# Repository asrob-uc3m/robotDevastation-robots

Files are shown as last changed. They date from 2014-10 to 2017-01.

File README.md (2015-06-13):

robotDevastation-robots
=======================

Bundle of robot software (firmware), electronics and mechanics.

1. [rd2](rd2/)
--------
[Cómo montar el robot RD2](http://asrob.uc3m.es/index.php/C%C3%B3mo_montar_el_robot_RD2)
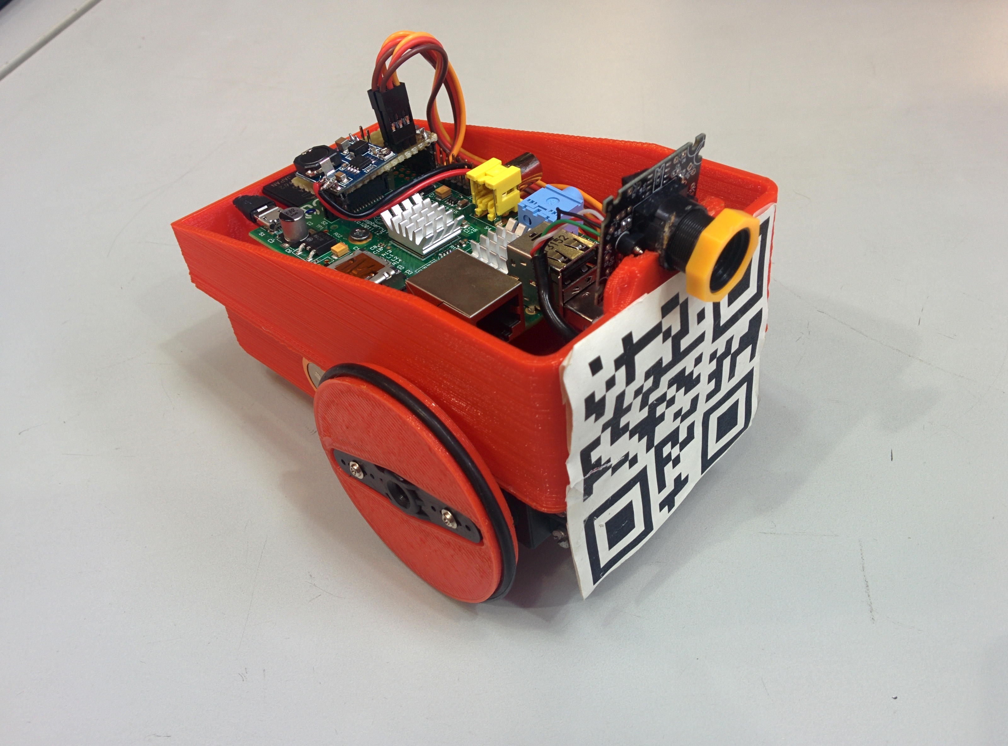
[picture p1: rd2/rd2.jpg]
RD2 robot


2. [ecro](ecro/)
--------
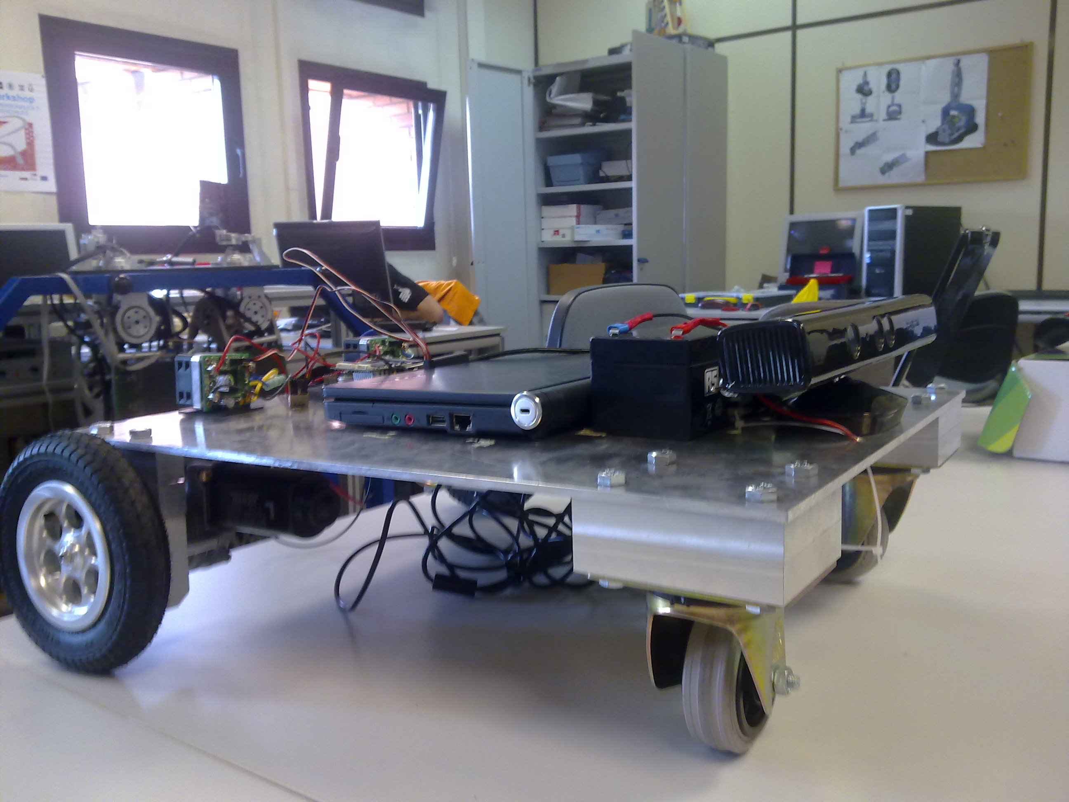
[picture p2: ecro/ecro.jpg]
ECRO robot


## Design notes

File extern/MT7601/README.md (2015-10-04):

MT7601 driver [copy from porjo]
===============================

Chipset is Ralink 148f:7601. Firmware is copied off https://github.com/porjo/mt7601/raw/master/src/mcu/bin/MT7601.bin

As of 4/Oct/2015 (reading: http://groenholdt.net/Computers/RaspberryPi/MediaTek-MT7601-USB-WIFI-on-the-Raspberry-Pi/MediaTek-MT7601-USB-WIFI-on-the-Raspberry-Pi.html), we updated to raspi kernel 4.1.9+ with: 
```bash
sudo -s
apt-get update
apt-get upgrade
rpi-update
```

Got a -2 error on direct load of firmware. The final step is (reading: https://www.raspberrypi.org/forums/viewtopic.php?t=119095&p=808311) to put the firmware .bin file (stored a copy in this directory) in /lib/firmware for raspi 4.1.9+.

Appears as wlan0, so the rest are standard configurations in /etc/network/interfaces and /etc/wpa_supplicant/wpa_supplicant.conf

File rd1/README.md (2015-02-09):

rd1
===
[Link to RD1 doxygen generated documentation](http://asrob.uc3m.es/rd1doc/index.html)
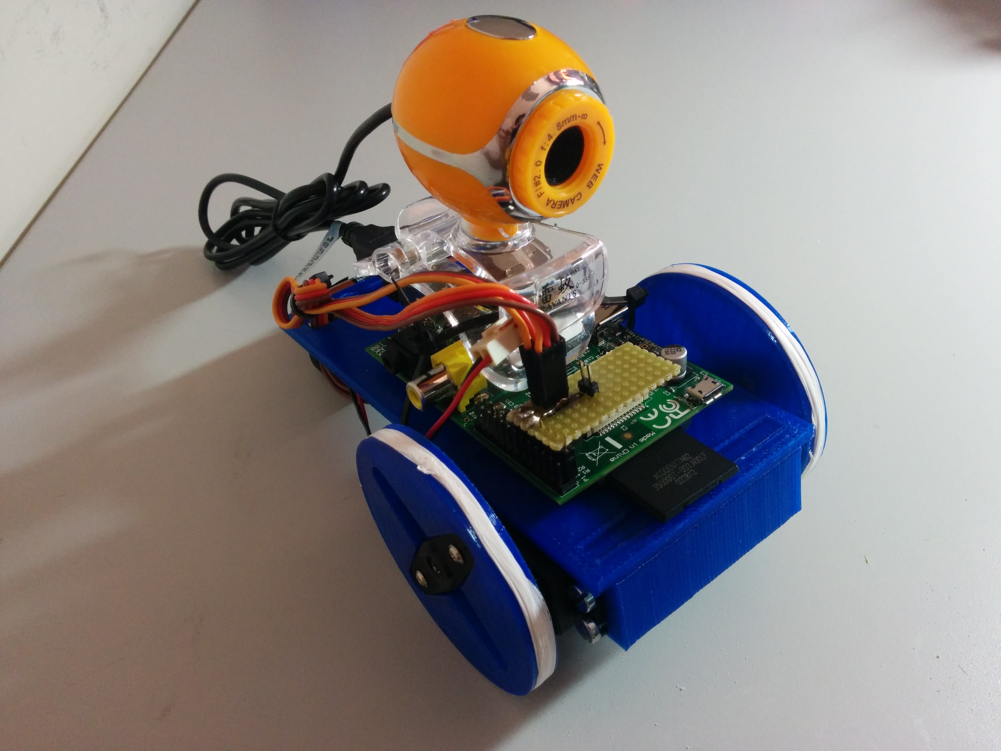
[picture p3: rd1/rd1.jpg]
RD1 robot


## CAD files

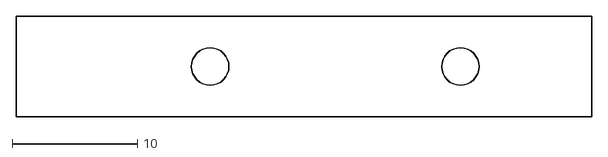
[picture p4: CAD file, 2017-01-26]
ecro/necro/motor holder.dxf
46.0 x 8.00

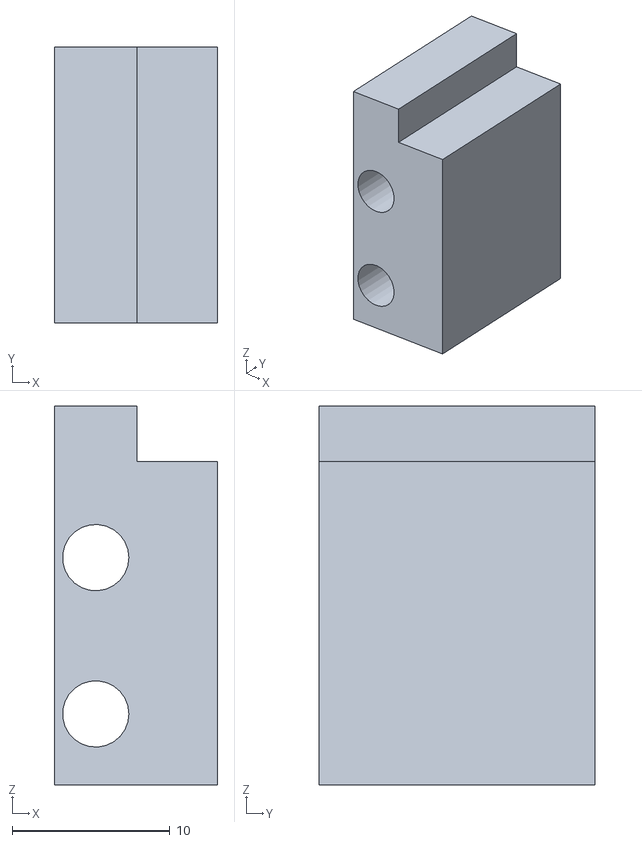
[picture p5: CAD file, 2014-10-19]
rd1/mechanics/rdSopportBack.stl
10.3 x 17.5 x 24.0

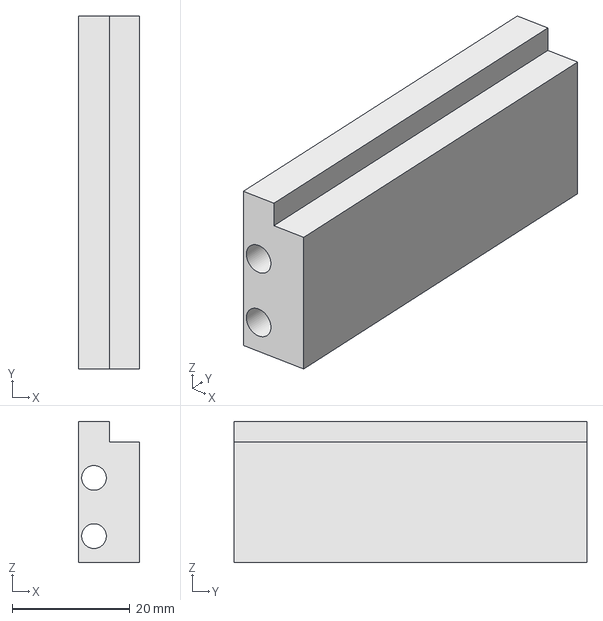
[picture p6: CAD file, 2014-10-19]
rd1/mechanics/src/rdSopportFront.FCStd
10.3 x 60.0 x 24.0 mm

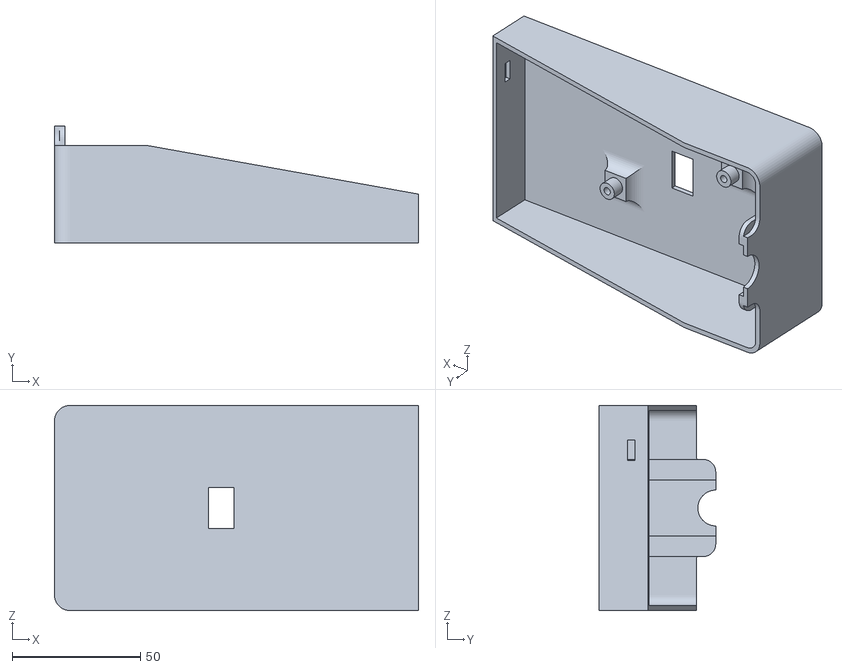
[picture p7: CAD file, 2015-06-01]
rd2/mechanics/oldversions/rd2TopV1_1.STL
142.0 x 45.5 x 80.0

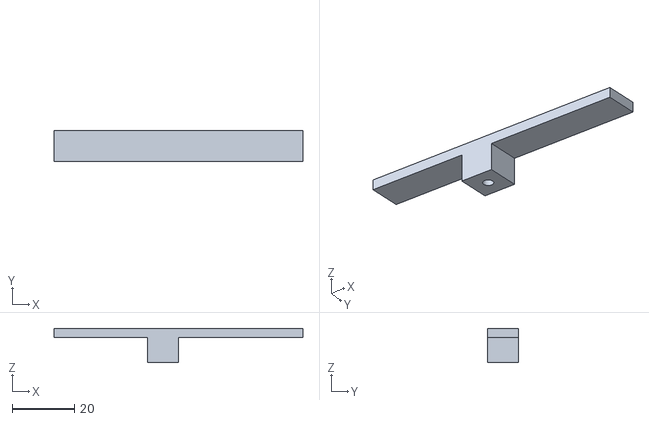
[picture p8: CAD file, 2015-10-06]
rd2/mechanics/rd2SoporteRaspberry1B_(2)V1_0.STL
80.0 x 10.00 x 11.0

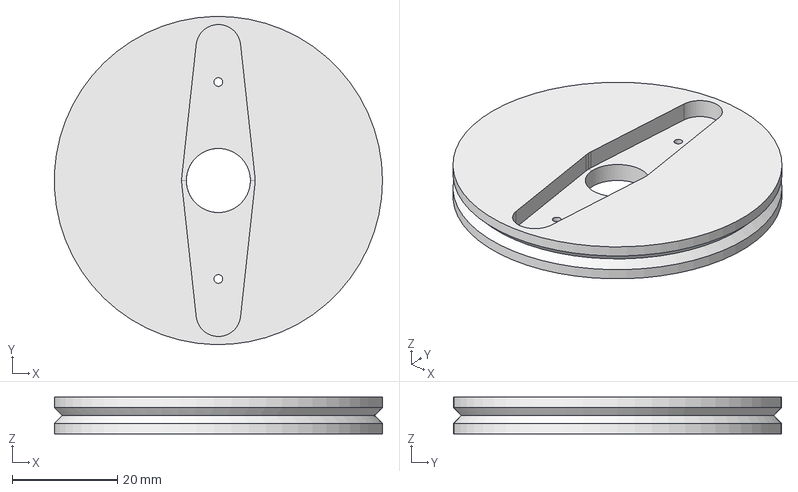
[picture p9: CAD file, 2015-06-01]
rd2/mechanics/src/rd2Wheel.fcstd
62.5 x 62.5 x 7.00 mm

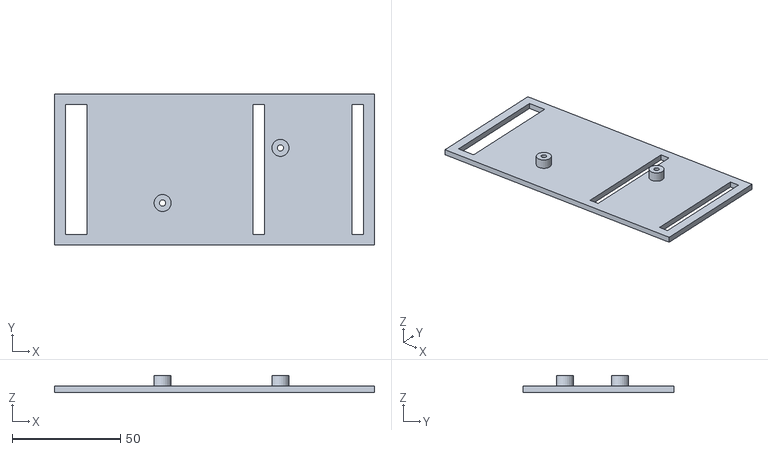
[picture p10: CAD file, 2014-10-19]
rd1/mechanics/rdTop.stl
148.0 x 70.0 x 8.00

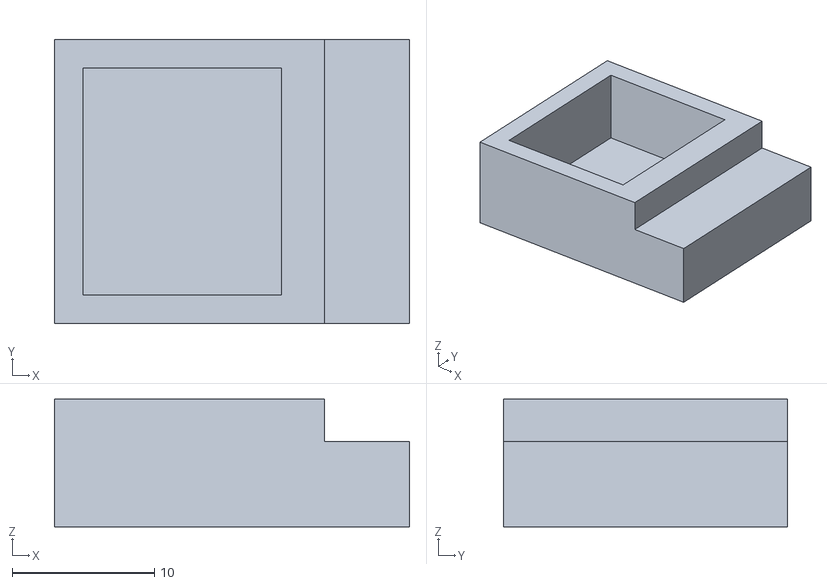
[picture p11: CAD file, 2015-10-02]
rd2/mechanics/rd2SoporteBateria_V1.0.STL
25.0 x 20.0 x 9.00

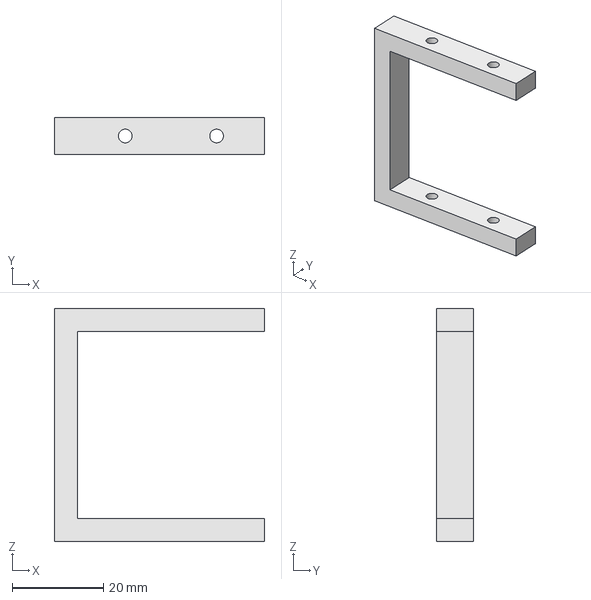
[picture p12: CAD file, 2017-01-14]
ecro/necro/motorDriverHolder.fcstd
46.0 x 8.00 x 51.0 mm

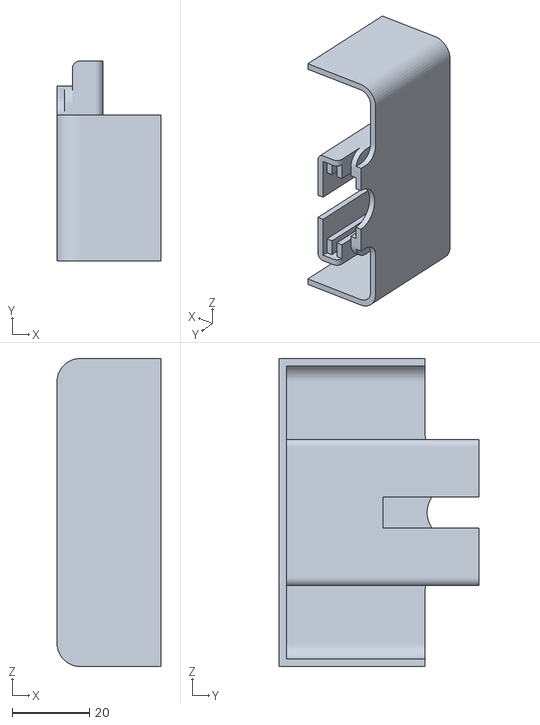
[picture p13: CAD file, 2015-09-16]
rd2/mechanics/rd2CameraTopV1_0.STL
27.0 x 52.0 x 80.0

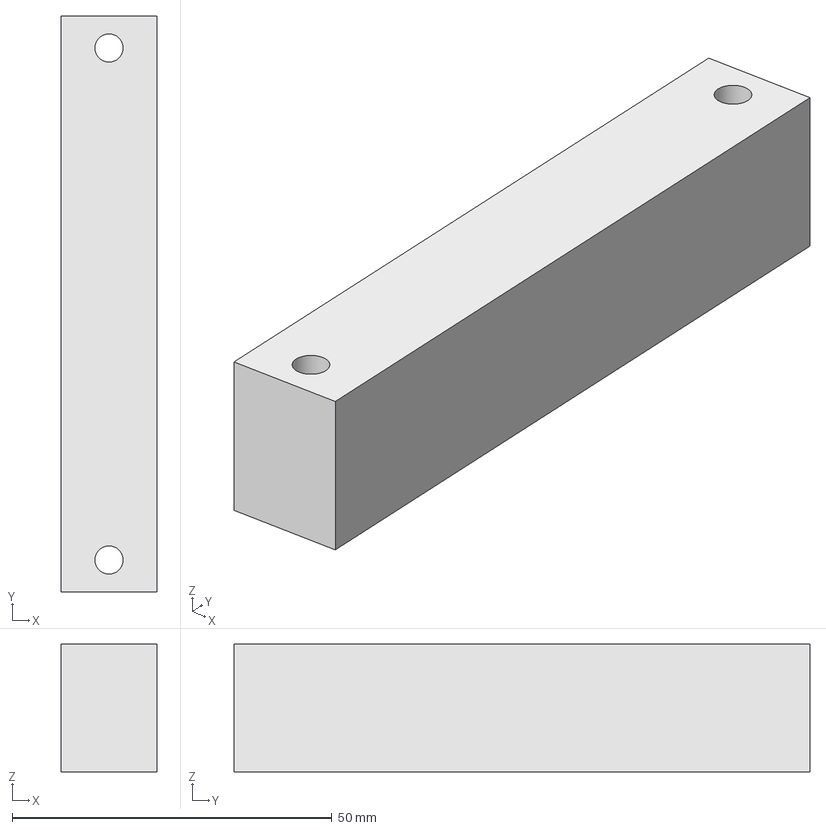
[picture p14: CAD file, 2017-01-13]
ecro/necro/supportB.fcstd
15.0 x 90.0 x 20.0 mm

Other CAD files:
ecro/necro/back template.fcstd
rd1/mechanics/src/rdSopportBack.FCStd
rd2/mechanics/rd2SoporteRaspberry1B_V1_0.STL
ecro/necro/front template.fcstd
rd1/mechanics/rdSopportFront.stl
rd1/mechanics/src/rdTop.FCStd
rd2/mechanics/rd2Wheel.STL
ecro/necro/back template.dxf
ecro/necro/front template.dxf
ecro/necro/motorDriverHolder.stl
ecro/necro/supportA.fcstd
ecro/necro/supportA.stl
ecro/necro/supportB.stl
rd2/mechanics/rd2BaseV1_0.STL

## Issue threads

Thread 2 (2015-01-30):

Upload image  of RD1 SD card.

jgvictores, 2015-01-30:
Can be uploaded as file in SF. Must set: default enable_pwmbot true, rc.local (before creating image).

David-Estevez, 2015-01-30:
@jgvictores What about making a 'distro' with everything ready / almost ready to just write the image in the sd card and play? Support to other platforms (Beaglebone, etc)?

jgvictores, 2015-01-30:
Yes, what I had in mind is getting what we already have (a raspian with launchRd1), set rc.local to launch launchRd1 (maybe through yarprun), and uploading that plug-and-play image (fsa  and/or raw dd).
It would be great to set up an apt-ppa, and port to many platforms. Let's keep this issue for keeping track of the rd1-raspian image, and open new issues for specific ports.

jgvictores, 2015-02-01:
Should check  tools that offer the possibility of a graphical front-end (Clonezilla, perhaps?).

David-Estevez, 2015-02-01:
A graphical front-end for uploading the image to the SD card? I used Clonezilla for backups in the past, and you still need to boot Clonezilla for that, so you have to write Clonezilla on another device.

Unetbootin worked for me when writing Live USBs from ISOs, but I guess it does not work the same way with Raspberry Pi images

jgvictores, 2015-02-08:
Two comments regarding deployment:
- I believe defaulting to using a yarprun daemon on the robots will prove useful. Yarprun is a server to launch and monitor programs remotely. This way, the robotDevastation PC can have all the setup options, and launch the corresponding robotDevastation-robots program with the correct arguments.
- We should consider Docker Hub Registry (https://registry.hub.docker.com/). Check the following currently ongiong thread: http://ros-users.122217.n3.nabble.com/Givving-ROS-an-Official-DockerHub-Image-td4021623.html

David-Estevez, 2015-02-08:
The daemon seems to be a good choice, this way the robot could be managed directly from the player's PC.

I didn't know about Docker, what a nice concept! We could definitely give in a try for shipping the game.

jgvictores, 2016-04-20:
The issue of the title has been closed a while ago (http://asrob.uc3m.es/index.php/C%C3%B3mo_montar_el_robot_RD2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), so closing.

Closed 2016-04-20.

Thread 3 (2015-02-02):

Have a usable and documented robot.

jgvictores, 2015-02-02:
Both rd1 and rd2 look like good candidates, but we need documentation on construction and installing software too for anyone to build it.

Rodriwp, 2015-02-02:
I think we must create documentation for rd2 ( with raspberry pi) as the standard robot for everyone and documentation for the "Ardubot module" that enables anyone with arduino and robotics skills to implement robot devastation in any project without linux skills or advance programming skills.

David-Estevez, 2015-02-02:
I would argue that controlling the board's GPIOs with python requires less skills than developing on Arduino, as well as reduce costs by removing the need of adding an extra board.

Anyway, this issue refered to the need of having any usable robot with documentation, rd2 (+ardubot or whatever is finally used) is perfectly suitable to solve this issue.

Btw, we have thought about using the new [Raspberry Pi 2](http://www.raspberrypi.org/raspberry-pi-2-on-sale/) or the [ODroid C1](http://www.hardkernel.com/main/products/prdt_info.php) as our choice of SBC, as it seems that that format of board with those holes and connectors is likely to become a standard among SBCs, and that will make easier to switch between one or other.

jgvictores, 2016-04-20:
Done at http://asrob.uc3m.es/index.php/C%C3%B3mo_montar_el_robot_RD2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, duplicate of #5.

Closed 2016-04-20.

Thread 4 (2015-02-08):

Battery Status

Rodriwp, 2015-02-08:
For the rd2 version with ardubot will be nice to have feedback about the state of the batteries. This version use lipo bateries for the motors and is dangerous to discharge below a certain voltage(the value depends on the number of cells)

Smallest robots probably, will have an approximated voltage measure. For the biggest robots that use ardubot, there exists an voltage regulator,amperage measure and voltage measure that cost about 10 euros.

Here is a link http://www.dx.com/es/p/zndiy-bry-apm2-5-2-apm2-6-power-module-v1-0-output-w-bec-3a-xt60-plug-black-red-342902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

http://copter.ardupilot.com/wiki/common-measuring-battery-voltage-and-current-consumption-with-apm/?lang=es
- [ ] Software (implementation)
- [ ] Hardware (assembly)

Rodriwp, 2016-10-22:
In the software part it will be useful to encapsulate in RdRobotLib some function about robot status. Right know we are only planning to  take information from the robot about battery status, but it should support in the future more robot information (gps position, gyroscope,etc).

Im working on it right know

Rodriwp, 2016-10-22:
I propose several states for the battery that are set using an integer.

- NOBATERRY for robots that don't use batteries.
- A value between 1 and 100 for the percentage of battery if is discharging
-  A value between 101 and 200 for the percentage of battery if is charging

jgvictores, 2016-10-22:
I was actually going to propose implementing the YARP [IBattery](http://www.yarp.it/classyarp_1_1dev_1_1IBattery.html) interface. Here's the raw of the file:
https://github.com/robotology/yarp/blob/e0ca8e6f73c37286734d06e3afb8015529ee36b9/src/libYARP_dev/include/yarp/dev/IBattery.h
I've seen they are implementing a yarpbatterygui, so this can be a good thing.

jgvictores, 2016-10-22:
Updated link in previous comment.

David-Estevez, 2016-10-22:
+1 to the existing interface.

IMHO, I think the focus should shift from the frontend side to the robot backend. It has no sense to implement the software support for battery status if we are not currently able to measure the battery status.

Rodriwp, 2016-10-22:
+1 to the existing interface too

@David-Estevez we already have a battery mesuared system. There is one in our closet

[APM POWER MODULE](https://es.aliexpress.com/store/product/Free-Shipping-airplane-APM-Power-Module-5-3V-DC-BEC-XT60-Connectors-for-ARDUPILOT-APM-2/2218173_32711885701.html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,searchweb201602_3_10065_10068_10069_10084_10083_10017_10080_10082_10081_10060_10061_10062_10056_10055_10054_10059_10078_10079_10073_10070_421_420_10052_10053_10050_10051,searchweb201603_7&btsid=33a392cf-9d4d-4365-a3bb-e7da754c687b)

This module is at the same a time a power regulator the will solve our two battery problem and it have also voltage and current mesuare.

And the best thing, it only cost 5 $

jgvictores, 2016-10-22:
> And the best thing, it only cost 5 $

:joy::joy::joy:

David-Estevez, 2016-10-22:
What I meant is that the most sensible approach, in my opinion, is a bottom-up approach: hardware -> firmware -> software , not the other way around.

Nevertheless, feel free to add support for such a magnificent piece of Chinese engineering, it will definitely be useful to have such data.

jgvictores, 2016-11-09:
@Rodriwp Could you please link to the current selected hardware?

Rodriwp, 2016-11-09:
I started some test with this device. It have six pins with the following pinout:

- 1 VCC +5
- 2 VCC +5
- 3 VCurrent
- 4 VBat
- 5  GND
- 6  GND
[Imagen Dispositivo](http://img2.banggood.com/thumb/large/upload/2014/03/SKU119430.0.jpg)
[PinOut](http://4.bp.blogspot.com/-L-IGAUheI_w/VfKFZQ2tWRI/AAAAAAAABMM/ztc3dOWLcUo/s1600/APM%2BPower%2Bmodule%2Bpinout.jpg)

Also, I have a code that can read the voltage of a battery using an analog input. As some of our robots, don't have analog input(raspberry pi), we can use an atiny85 to map de data and send via serial port.

This module is at the same time a power regulator, so we can use the same baterry for the motors and the raspberry pi.

Rodriwp, 2016-11-09:
@jgvictores  this is a link to the product [POWER MODULE 1.0](https://es.aliexpress.com/store/product/Wholesale-1pcs-2-5-APM-Flight-Controller-Power-Module-V1-0-Output-BEC-3A-Deans-T/603538_32547524353.html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,searchweb201602_2_10092_10091_10090_10088_10089,searchweb201603_1&btsid=2feb4319-315b-4998-b77c-53a0af2943b0)

jgvictores, 2016-11-09:
@Rodriwp Great, now could you link to a URL that describes the pinout?

Rodriwp, 2016-11-09:
@jgvictores you can find the schematics of the module [here](https://upverter.com/erlerobot/a9bdc322cf64f8a1/APM25-Power-Module-v10/)

Rodriwp, 2016-11-09:
@jgvictores in a comment below you cand find the pinout. Here the link [PinOut](http://4.bp.blogspot.com/-L-IGAUheI_w/VfKFZQ2tWRI/AAAAAAAABMM/ztc3dOWLcUo/s1600/APM%2BPower%2Bmodule%2Bpinout.jpg)

Rodriwp, 2016-11-09:
Extra information about our device:
The schematics of the module [here](https://upverter.com/erlerobot/a9bdc322cf64f8a1/APM25-Power-Module-v10/)

jgvictores, 2016-11-09:
@Rodriwp As general questions related to the battery (NOT the power module):
1. What is the battery voltage range (Vmin-Vmax) we are expecting to read?
2. What is the battery current range (Imin-Imax) we are expecting to read

Rodriwp, 2016-11-23:
1. We are expecting between 3.7 and 4.1 volts per celd, and we excpected 2 and 3 cell bateries
2. We are expecting between 0 A and about 0.6 A for standar robots. More powerfull robots as RD glory, needs about 1.2A. We should support both ranges.

jgvictores, 2016-11-23:
Please focus on one specific model. Which one?

Rodriwp, 2016-11-23:
We can focus on 2 cells 0.8 max A robots

David-Estevez, 2016-11-23:
Please specify also the estimated current comsuption per device (e.g. SBC, motors (nominal and allowed peaks), camera, etc).

Rodriwp, 2016-11-23:
The RD2 have the following parts:

1. Motors: 200mA peak 300mA x 2 motors
2. Camera: 200mA
3. RaspberryPi: 800mA
4. WifiModule: 215mA

Total: 1.8 A of current expected.

jgvictores, 2016-11-23:
Okay, so that would be...
1. Sum of peak: 1.815 A
2. Sum of nominal: 1.615 A

Rodriwp, 2016-11-23:
The current arquitecture connects the motors directly to the battery, and all the other stuff through a 5V regulator.

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

jgvictores, 2016-11-23:
Could you please provide a link to the motors, which includes the maximum voltage?

Rodriwp, 2016-11-23:
The operating voltage is between 4.8 and 7.2

Rodriwp, 2016-11-23:
I propouse to use this solution
http://controlrobotics.rodrigomompo.com/2013/10/tutorial-battery-charge-indicator.html

jgvictores, 2016-11-23:
> The operating voltage is between 4.8 and 7.2

Seems the schematic would burn these motors.

> I propouse to use this solution

I understand you do not like your original proposal(s). Could you please upload an image of a new version of the schematic (including all components e.g. motors and RasPi) as a post on this issue?

Rodriwp, 2016-11-23:
As the current configuration of RD is deprecated, we should develop for RD ambassador #21.
Furthermore, I think the batery status, for simplicity could take into account only voltage measure.

For this aproach we only need to measuare the battery voltage before all the robot. So, we really don't care about the complete configuration.

jgvictores, 2016-11-23:
> As the current configuration of RD is deprecated, we should develop for RD ambassador #21.
Furthermore, I think the batery status, for simplicity could take into account only voltage measure.

The robot was never specify in this issue. Could you specify the robot in this issue?

BTW, there are no deprecated RD configurations I'm aware about. Could you please point to this fact if it exists?

> For this aproach we only need to measuare the battery voltage before all the robot. So, we really don't care about the complete configuration.

That's a design decision you can specify as the creator of this issue. Could you specify this as your objective?

Rodriwp, 2016-11-23:
RD2 use two batteries. Our current developments use only one battery. This is the reason why I said is deprecated

The objective of this issue is to measure the voltaje of the battery, as a digital output. We want to know when the battery is near to the dangerouts zone (7.6 v) and when we need to disconect the battery (7.4v)

jgvictores, 2016-11-23:
> RD2 use two batteries. Our current developments use only one battery. This is the reason why I said is deprecated

RD2 not dead! :smile:
I would definitely not DEPRECATE [our most documented robot](http://asrob.uc3m.es/index.php/C%C3%B3mo_montar_el_robot_RD2) yet.

> The objective of this issue is to measure the voltaje of the battery, as a digital output. We want to know when the battery is near to the dangerouts zone (7.6 v) and when we need to disconect the battery (7.4v)

This seems reasonable, at least to me.

David-Estevez, 2016-11-23:
> The objective of this issue is to measure the voltaje of the battery, as a digital output. We want to know when the battery is near to the dangerouts zone (7.6 v) and when we need to disconect the battery (7.4v)

Usually when using the robot the battery voltage decreases. So 7.6V would never be a problem in normal use. And if we disconnect at 7.4V (the typical battery value)  we wont ever play.

Rodriwp, 2016-11-23:
We should check the values

We already have one module working, we can use it for testing the firmware and software implementation

jgvictores, 2016-11-23:
What do you mean by checking?

Which module do you mean?

Rodriwp, 2016-11-23:
We should adjust the alarm values to the safety lipo operation range

The circuit that is explain in http://controlrobotics.rodrigomompo.com/2013/10/tutorial-battery-charge-indicator.html, we have that circuit with us

jgvictores, 2016-11-23:
> We should adjust the alarm values to the safety lipo operation range

What do you mean by  that?

> The circuit that is explain in http://controlrobotics.rodrigomompo.com/2013/10/tutorial-battery-charge-indicator.html, we have that circuit with us

Could you please provide a schematic that includes the components (a paper version like the previous would do)?

Rodriwp, 2016-12-15:
I won't continue this idea as it lead to stalemate

David-Estevez, 2017-06-14:
I guess it is the moment to really solve this.

David-Estevez, 2017-06-14:
https://www.youtube.com/watch?v=md3B3I7Nmvw

jgvictores, 2017-06-15:
> Lashing out the action, returning the reaction
[...]
Battery is found in me
Battery
Battery

JavierIH, 2017-06-15:
:popcorn:

jgvictores, 2018-05-13:
Ongoing PR: https://github.com/robotology/yarp/pull/1583

jgvictores, 2018-06-22:
Moved to https://github.com/asrob-uc3m/robotDevastation-research/issues/11

Closed 2018-06-22.

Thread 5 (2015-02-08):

RaspberryPi + rd1 Set Up Guide

Rodriwp, 2015-02-08:
Will we nice to have a complete guide about seting up raspberrypi without using the image of rd1. The documentation also will help with rd2 with ardubot   and ardubot versions.

jgvictores, 2015-02-09:
This issue is almost a duplicate of https://github.com/asrob-uc3m/robotDevastation-robots/issues/3, but we can use it to focus on RD1. For now the two relevant links are:
- http://asrob.uc3m.es/rd1doc/rd1_install_on_raspbian_7.html
- http://asrob.uc3m.es/index.php/C%C3%B3mo_montar_el_robot_RD1

jgvictores, 2015-06-03:
RD1 depreciated. Docuemented RD2 at http://asrob.uc3m.es/index.php/C%C3%B3mo_montar_el_robot_RD2.

Closed 2015-06-03.

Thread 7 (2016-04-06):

RD3 and RDTurret (...and other ideas)

JuanFdelArco, 2016-04-06:
New robot design assigned to Juan F. del Arco.

David-Estevez, 2016-04-06:
@JuanFdelArco when you are more o less done with the design of the new RDTurret I can help you setup a stereo camera to have a 3D First Person View of the Turret's point of view with a phone (and old project of mine) :smile:

JuanFdelArco, 2016-04-13:
Idea #1:
- Omnidirectional robot.
- There are QR's on each corner.
- It can be combined with RDTurret for two players on one robot.

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

David-Estevez, 2016-04-13:
@JuanFdelArco Very cool robot!!

David-Estevez, 2016-04-13:
Suggestion for the wheels:
* http://www.robotshop.com/en/58mm-plastic-omni-wheel-lego-nxt-servo.html
* http://www.robotshop.com/en/48mm-omniwheel-lego-nxt-servo.html

David-Estevez, 2016-06-01:
Looking for "robot tracks" in aliexpress: http://es.aliexpress.com/store/product/Free-shipping-smart-Car-Smart-Car-Chassis-Robot-Tracking-Sensor-Coded-Disc/1460814_32288410589.html

David-Estevez, 2016-06-02:
More ideas: use stock batteries from consumer electronics products (such as cameras, smartphones, etc)

Example: http://es.aliexpress.com/store/product/2pcs-Battery-Charger-7-4V-1800mAh-EN-EL9-EN-EL9-ENEL9-Rechargeable-Camera-Battery-For-Nikon/1163277_1797911243.html

David-Estevez, 2016-06-14:
Even more ideas: [Cool Fighting Robots](https://www.youtube.com/watch?v=BgOG5te3jlc) via @JavierIH

(Maybe all this info should be moved to [robotDevastation-research](https://github.com/asrob-uc3m/robotDevastation-research))

jgvictores, 2018-06-22:
This issue was moved to asrob-uc3m/robotDevastation-research#10

Closed 2018-06-22.

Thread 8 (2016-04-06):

Robot (first time) configuration through access point

David-Estevez, 2016-04-06:
Suggestion for a cool improvement: When you first turn on you robot, it creates a wireless access point that you can use to configure the robot and tell which network it should connect to. Then, the robot switches off this access point and connects to the game network.

jgvictores, 2017-02-17:
Blocked by #29

jgvictores, 2017-03-29:
Unblocked as #29 closed.

The proposed interface should modify the installed versions of [these launch files](https://github.com/asrob-uc3m/robotDevastation-robots/tree/fd9f832c0a2a62b61b27aa2062626e6d0901e8bf/share/launch), which are currently hard-coded to be used from `/usr/local/share/robotDevastation-robots/contexts/launch/` in [the services](https://github.com/asrob-uc3m/robotDevastation-robots/tree/fd9f832c0a2a62b61b27aa2062626e6d0901e8bf/scripts/etc/service).

As an additional reference, we still have [this web snippet](https://github.com/asrob-uc3m/robotDevastation-robots/tree/fd9f832c0a2a62b61b27aa2062626e6d0901e8bf/web), but it lacks editing permissions on the installed files.

jgvictores, 2018-04-13:
Historic from http://asrob.uc3m.es/index.php/C%C3%B3mo_instalar_el_software_de_RD1_sobre_Raspbian_7 ([perma](http://asrob.uc3m.es/index.php?title=C%C3%B3mo_instalar_el_software_de_RD1_sobre_Raspbian_7&oldid=11274)):
```
git clone https://github.com/asrob-uc3m/robotDevastation-robots.git  # Download the robotDevastation-robots software from the repository
cd robotDevastation-robots/rd1/software; mkdir build; cd build; cmake ..  # Configure the robotDevastation-robots RD1 software
make  # Compile
sudo make install  # Install :-)

#- Extra robotName config server:
sudo apt-get install php5
sudo ln -s web/index.php /var/www
sudo ln -s web/save.php /var/www
```

jgvictores, 2019-05-07:
Setting up a Raspberry Pi as an access point in a standalone network (NAT): https://www.raspberrypi.org/documentation/configuration/wireless/access-point.md

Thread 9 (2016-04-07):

Decrease video transmission latency

Rodriwp, 2016-04-07:
In order to decrease latency, test if this modules are better than the current ones

David-Estevez, 2016-04-07:
ESP8266 modules aren't USB WiFi dongles, but bridges between USARTs and TCP/UDP sockets on the PC side. Therefore, I doubt that they can be used to stream images from the raspberry pi (and if they can, it's probably through a even slower connection).

To reduce latency (if that is the issue), two approaches can be followed:

1. Upgrade cheap WiFi dongle with a higher quality (Bandwidth) one. I can lend you one ASUS N11 dongle I have at home for testing.
2. Try to view a mjpeg stream directly using mjpg-streamer on the raspberry pi. If using only mjpg-streamer the video doesn't have any latency, this latency might be introduced by the image processing done on the PC (not related to WiFi hardware).

jgvictores, 2016-04-07:
Option 2 involves invoking mjpg_streamer on the raspi, as in:
`mjpg_streamer -i "input_uvc.so -f 15 -d /dev/video0 -y" -o "output_http.so -p 8080"`
It's good because we'd drop some wrapping processes involved in using opencv and yarp on the raspi side. We could then hook the stream on the robotDevastation (PC client) side as we did in https://github.com/robotology/yarp/issues/254 (with a Darwin-op robot using mjpg_streamer: https://sourceforge.net/projects/mjpg-streamer/).

David-Estevez, 2016-04-07:
Another possible related software improvement could be print the received images _before_ further processing (to have a higher update rate) and process only a few frames (use tracking to interpolate enemies between frames).

jgvictores, 2016-04-08:
Ok to change the topic to **Decrease video transmission latency**?

Rodriwp, 2016-04-10:
RaspiMjpeg seems to solve the problem.
https://www.raspberrypi.org/forums/viewtopic.php?f=43&t=61771
Next sesion I will test it

David-Estevez, 2016-04-23:
Some new points:

1. Last wednesday we tested the wifi connection and it was ok between two PCs on the same LAN, so the problem must be related to the robot. Next thing to try is changing the wifi dongle by a faster one, to check if high latency is related to wifi dongle bandwidth.
2. Related to use the ESP8266 as wifi dongle, I have found the following resources:
    * https://hackaday.io/project/8678-rpi-wifi
    * https://github.com/al177/esp8089

    It is a difficult issue, and I'm not sure that this solution is faster that the current chinese wifi dongle.

Rodriwp, 2016-11-09:
The next test we need to perform is with RD2 Black and @David-Estevez expensive wifi module. So, we can discard that our chinese hardward is the problem

Rodriwp, 2016-11-23:
@David-Estevez  and @jgvictores Did you realize if RD ambassador decrease transmission latency ?

jgvictores, 2016-11-23:
Yesteday at https://github.com/asrob-uc3m/actas/issues/36 latency was surprisingly low.

It would be great if you could stay focused on #4 for the time being.

jgvictores, 2018-05-08:
Just for the record, I've read one of the greatest improvements on `Raspberry 3 B+` is on comms, note the 2.4GHz and 5GHz IEEE 802.11.b/g/n/ac wireless LAN spec: https://www.raspberrypi.org/products/raspberry-pi-3-model-b-plus/

jgvictores, 2018-06-22:
This issue was moved to asrob-uc3m/robotDevastation-research#13

Closed 2018-06-22.

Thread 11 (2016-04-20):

[cmake] Set up cross compiling for raspi

jgvictores, 2016-04-20:
[cmake] Set up cross compiling for raspi

help: https://blog.kitware.com/cross-compiling-for-raspberry-pi/

David-Estevez, 2016-10-19:
More info: http://hackaday.com/2016/09/01/how-to-use-docker-to-cross-compile-for-raspberry-pi-and-more/

jgvictores, 2018-06-22:
This issue was moved to roboticslab-uc3m/yarp-devices#186

Closed 2018-06-22.

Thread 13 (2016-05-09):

Use ARM Cortex M

Rodriwp, 2016-05-09:
I buy for 2$ an ARM Cortex M3. As this hardware seems to be more powerfull, let's test if we can do ip video with it. Probably a bundle arm cortex m3 + esp8266 could be the core of the new low cost robots.

If M3 is not powerfull enoght we can test M4 and M7. With this we can create the robot devastation board.

David-Estevez, 2016-05-09:
This comment has two parts: one in which I warn you about why this is difficult and another in which I provide you some resources just in case you still want to try to do this.

First of all, if you want to have a achieve transmission rate, you won't be using Arduino-like libraries to program the ARM chip, but manipulating raw registers and memory. You will have to find out what is the protocol for image transmission in the camera module, what is the image format, and what is the compression algorithm used (if it has any). Then,  you will have to implement a socket-based streamer to transmit the image data. You may have or not to encode the data in each packet, but still you will have to implement all the streamer code (take a look of mjpg-streamer code, for instance) in the ARM chip. Take into account also debugging of the code, which will be also difficult as it involves several pieces of hardware and image processing.

If after all of this you still want to build this device, here you have some resources that might be useful for you:

* This [post in hackadaty](https://hackaday.com/tag/wifi-camera/) shows an existing implementation of a DIY WiFi camera done with the M3 in the ESP8266 board.
* This comment in other related issue: https://github.com/asrob-uc3m/robotDevastation-robots/issues/9#issuecomment-213746159 gives you some clues about the WiFi transmission part.

David-Estevez, 2016-05-09:
FYI: http://es.aliexpress.com/store/product/WIFI-1280-x-960P-1-3MP-Mini-IP-Camera-Indoor-Black-Security-Camera-Night-Vision-ONVIF/415422_32573773191.html

Rodriwp, 2016-05-09:
Probably It will be nice to use 0V7670 camera. It cost around 3'50$ and is a well know camera with a lot of information. A full robot devastation pcb with 4 motor ports and a battery could be achive between 10$ and 15$ if this works.

Rodriwp, 2016-11-23:
As raspberry pi zero cost only 5$ and the purpose of this issue is deacrease the cost, right know it not make sense this aproach.

Closed 2016-11-23.

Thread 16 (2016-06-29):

yarprun service on RD network nodes does not always connect to yarp server

jgvictores, 2016-06-29:
The current use of daemontools makes yarprun run sometimes without connecting to the yarp server.
A `yarp detect` or similar (checking the return value) should be included in the daemontools service script (`/etc/service/yarprun`) or even completely replace daemontools for a different method to avoid this.

jgvictores, 2017-02-15:
This issue appeared when `yarprun` began spawning two processes (two PID). Closing, as in #29 we propose to drop `yarprun`.

Closed 2017-02-15.

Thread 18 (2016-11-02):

LaserTowerOfDeath resurrection (FW)

David-Estevez, 2016-11-02:
LaserTowerOfDeath resurrection (FW)

jgvictores, 2016-11-11:
Started with this at https://github.com/asrob-uc3m/robotDevastation-robots/commit/f5c96582a1b3b2966d89e5a4bcc46a50987bf776
However. @David-Estevez pointed to https://github.com/asrob-uc3m/robotDevastation/releases/tag/dead-newApproach ...mush check!

jgvictores, 2016-12-07:
Currently at https://github.com/asrob-uc3m/robotDevastation-robots/tree/develop/firmware/arduinoServer

jgvictores, 2016-12-07:
Finished at 8b92d2ca2277314bc19fde20e4be960bb1d7b070

Closed 2016-12-07.

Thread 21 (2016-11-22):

Document RD "Ambassator"

David-Estevez, 2016-11-22:
Document our new robot model RD "Ambassator" (named that way because its made from parts from "Electrónica Embajadores")

- [x] Electronics (and assembly)
- [x] BOM (and finding substitutes)
- [x] Calibration (related to electronics)
- [x] Block diagram
- [x] Add http://wiringpi.com/download-and-install/ as software dependency.

David-Estevez, 2016-11-24:
@jgvictores Build documentation for this robot would go in the [developer manual](https://github.com/asrob-uc3m/robotDevastation-developer-manual) or in the [user manual](https://github.com/asrob-uc3m/robotDevastation-user-manual) ??

jgvictores, 2016-11-24:
I'd put it in the user manual, as [the closest we have to a user guide](http://asrob.uc3m.es/index.php/C%C3%B3mo_empezar_con_Robot_Devastation) includes instructions for building a robot.

Closed 2017-05-31.

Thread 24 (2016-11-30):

Old Glory Proyect

Rodriwp, 2016-11-30:
The idea of this issue is to track the development of the Old Glory resurection.

This robot will implement #4, so we can test and close that issue.

This robot will work with a joystick in the first test and then will we suported by robotdevastation.

Closed 2016-12-15.

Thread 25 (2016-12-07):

Document installation including dependencies

jgvictores, 2016-12-07:
- [x] Wiring for raspi
- [x] libserial-dev for LaserTowerOfDeathController

jgvictores, 2017-01-18:
Done at https://github.com/asrob-uc3m/robotDevastation-user-manual/commit/90acc7063445f4ddad9b7f37343a3d05c5b825b5

jgvictores, 2017-01-23:
Missing:
- [ ] Several `cd`commands so all will be done at same level
- [ ] `sudo apt-get update` before anything.

jgvictores, 2017-01-25:
Finished at fb0cdfaeb46fa7067699dd220ab777cbe898cb3d.

Closed 2017-01-25.

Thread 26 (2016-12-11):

Improve launching robots: decide on which to focus.

jgvictores, 2016-12-11:
E.g.
- Remote robots such as RD1, RD2, and potentially RD "Ambassator" (see #21) still suffer from #16.
- LaserTowerOfDeath mainly lacks documentation, see #25.

David-Estevez, 2016-12-11:
The original roadmap proposed working with "wired" robots (i.e. turrets) because they are (in principle) easier to setup and easier to work with when developing the game.

So I vote for working on turret-like robots first, and them move on remote robots.

It is outside the scope of this repo, but we also have to have in mind (milestone 5)[https://github.com/asrob-uc3m/robotDevastation/milestone/5] from RobotDevastation main repo.

jgvictores, 2017-02-15:
Software-wise:
- Locally connected turrets are supported, see [Launch Robot Devastation - With Fake Motors And With PC Webcam](https://github.com/asrob-uc3m/robotDevastation-user-manual/blob/a91657b481702fd1a795322e68d017efca3b3665/en/launch-robot-devastation---LaserTowerOfDeath-with-webcam.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). ToDo:
  - [ ] https://github.com/asrob-uc3m/robotDevastation/issues/91
- Remotely connected turrets have multiple issues. To name some:
  - [ ] #29
  - [ ] #9

jgvictores, 2017-05-24:
More related: #21 #34

jgvictores, 2017-12-01:
Will focus on simulated robots for now, see #36

Closed 2017-12-01.

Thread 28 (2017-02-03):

Rd hardware renewal

David-Estevez, 2017-02-03:
Decide what hardware has to be bought/replaced.

jgvictores, 2017-02-03:
1. Router

David-Estevez, 2017-02-03:
2. Caja ECRO?

David-Estevez, 2017-02-04:
3. Wheel controller

jgvictores, 2017-05-24:
> 3. Wheel controller

Unfortunately, I believe ECRO wheel controller is only sold within a 2-wheel kit https://www.parallax.com/product/28962

jgvictores, 2018-03-21:
Related: https://github.com/asrob-uc3m/impresoras-asrob/issues/56

jgvictores, 2018-06-22:
Router is WIP at https://github.com/asrob-uc3m/impresoras-asrob/issues/56, general topic not very hot at the moment (working on "revival" issues).

Closed 2018-06-22.

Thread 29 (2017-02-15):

Replace yarprun by list of services parsed from file

jgvictores, 2017-02-15:
Replace yarprun by list of services (motors, camera...) parsed from file.

The file could be modified by a service such as the proposed in #8.

jgvictores, 2017-02-15:
Current scripts can contain a `yarp detect`.

David-Estevez, 2017-02-16:
Just in case... To setup the autostart of a wiki in my server I used [systemd](https://wiki.archlinux.org/index.php/Systemd) and the command `systemctl` successfully.

jgvictores, 2017-03-08:
Progress being done on black RD2 "robotera", in branch `issue-29-replace-yarprun`, around 9c27066f39cc93f71c00fa08f3aa1b5865407d7.
Progress is slow due to compilation on Raspi1 (bump #11).
1. Compiled [yarp 2.3.68+181-20170203.11+gite122128](https://github.com/roboticslab-uc3m/installation-guides/blob/4a9cf4ca9d3a50b5237d8248faaeaaf1de0ed635/install_yarp.md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) to avoid compilation errors.
2. Am recompiling without `SKIP_ACE`, because shared libraries were not being loaded.

jgvictores, 2017-03-15:
Help: https://isotope11.com/blog/manage-your-services-with-daemontools

jgvictores, 2017-03-22:
Replaced `yarprun` service by two services (`launchCamera` and `launchRobot`) at c65f8bc3ce9e65db5bd3556b99c81cf495dfc816, hard-coded for `RaspiOnePwmMotorController` used on black RD2 (a.k.a. `rd2old` and `robotera` :smile:).
Next steps:
- [ ] Document process (or automate!) of copying services from `robotDevastation-robots/scripts/etc/service` to OS '/etc/service`.
- [ ] Parse config from file as proposed by this issue.

jgvictores, 2017-03-29:
Done at fd9f832c0a2a62b61b27aa2062626e6d0901e8bf.

Closed 2017-03-29.

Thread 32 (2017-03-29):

Smaller Raspberry image size

David-Estevez, 2017-03-29:
Since we are not using the whole Raspian (think about the graphical interface, for instance) we can decrease the size of the image for the release.

Refs:
* http://www.cnx-software.com/2012/07/31/84-mb-minimal-raspbian-armhf-image-for-raspberry-pi/
* https://github.com/andrius/build-raspbian-image
* http://www.cnx-software.com/2012/07/31/84-mb-minimal-raspbian-armhf-image-for-raspberry-pi/

jgvictores, 2017-12-02:
Haven't seen refs, but this could be done via `fsarchiver` as done [elsewhere](https://github.com/roboticslab-uc3m/yarp-devices/issues/43).

jgvictores, 2019-06-25:
Just to clarify:
- The `dd` mechanism used at time of writing creates larger images than `fsarchiver` which is being studied at time of writing
- The original purpose of this issue is effectively reducing the OS disk usage size, e.g. by removing GUI components, which would directly result in a smaller image via `fsarchiver`

jgvictores, 2020-05-17:
Update: `fsarchiver` was successfully used at https://github.com/asrob-uc3m/rd-ambassador/issues/1#issuecomment-503223715

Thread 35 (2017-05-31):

Orange Pi Lite robot

David-Estevez, 2017-05-31:
Rd Ambassador was ok, but it has several flaws that are hard to solve, the main one being that there are too many things to put on the mobile platform, and not enough space (camera, QR, Raspberry Pi...).

So I have started the development of a cool mobile robot to be the documented basic robot to be used in Robot Devastation.

The basic features it will have are:

* Instead of Raspberry Pi, it will use an Orange Pi Lite. The advantages of these board are the low cost, small size, and integrated WiFi card. We are also researching the possibility of using a camera connected to the camera bus of the board (does not require USB).
* Camera (either USB webcam or camera connected to camera bus).
* A shield for the Orange Pi with the following elements:
    * H-bridge or similar motor controller for 2 DC motors
    * Battery status feedback (related to #4 )
    * Regulator (which might be placed outside the board if we find that it is a better solution).
    * LEDs for status feedback
    * Buttons for user input
* It will use consumer camera batteries (or similar), that are easy to source as replacements, cheap and have their own safe and easy-to-use charger.

jgvictores, 2017-05-31:
- https://forum.armbian.com/index.php?/topic/3054-quality-of-images-from-orange-pi-pc-camera-module/
- http://192.241.128.247/2016/04/05/orange-pi-camera-with-v4l2loopback-vidcopy/

jgvictores, 2017-05-31:
- http://192.241.128.247/2016/04/05/orange-pi-camera-with-v4l2loopback-vidcopy/ -> [orangePiCamera.pdf](https://github.com/asrob-uc3m/robotDevastation-robots/files/1042437/orangePiCamera.pdf)

jgvictores, 2017-05-31:
```
./vidcopy -w 800 -h 600 -r 20 -i /dev/video0 -o /dev/video1 -f UYVY
Required width: 800
Required height: 600
Required FPS: 20
input device: /dev/video0
output device: /dev/video1
Driver Caps:
  Driver: "sunxi-vfe"
  Card: "sunxi-vfe"
  Bus: "sunxi_vfe sunxi_vfe.0"
  Version: 1.0
  Capabilities: 05000001
  FMT : CE Desc
--------------------
  422P:    planar YUV 422
  YU12:    planar YUV 420
  YV12:    planar YVU 420
  NV16:    planar YUV 422 UV combined
  NV12:    planar YUV 420 UV combined
  NV61:    planar YUV 422 VU combined
  NV21:    planar YUV 420 VU combined
  HM12:    MB YUV420
  YUYV:    YUV422 YUYV
  YVYU:    YUV422 YVYU
  UYVY:    YUV422 UYVY
  VYUY:    YUV422 VYUY
  BA81:    RAW Bayer BGGR 8bit
  GBRG:    RAW Bayer GBRG 8bit
  GRBG:    RAW Bayer GRBG 8bit
  GRBG:    RAW Bayer RGGB 8bit
  BG10:    RAW Bayer BGGR 10bit
  GB10:    RAW Bayer GBRG 10bit
  BA10:    RAW Bayer GRBG 10bit
  BA10:    RAW Bayer RGGB 10bit
  BG12:    RAW Bayer BGGR 12bit
  GB12:    RAW Bayer GBRG 12bit
  BA12:    RAW Bayer GRBG 12bit
  BA12:    RAW Bayer RGGB 12bit
Selected Camera Mode:
  Width: 640
  Height: 480
  PixFmt: UYVY
```

David-Estevez, 2017-06-04:
After reading the post a bit more in detail, it seems that there is a parameter, `VIDIOC_S_INPUT` that has to be configured for this camera to work, but most v4l2-based programs leave unconfigured by default.

I adapted his function `v4l2_set_input` to work with `mjpeg-streamer`'s `input_uvc` plugin, and called it before the initialization of the camera. This removes the error from the `mjpeg-streamer`'s output and allows streaming of the camera without `v4l2-loopback`. The adapted function looks like this:
```cpp
int v4l2_set_input(struct vdIn *dev) {
	/*
	 * define video input
	 * vfe_v4l2 the driver is forced to input = -1
	 * set as the input = 0, works fine.
	 */
	struct v4l2_input input;
	int count = 0;
        memset(&input, 0, sizeof(struct v4l2_input));
	input.index = count;
	while(!xioctl(dev->fd, VIDIOC_ENUMINPUT, &input)) {
		input.index = ++count;
	}
	count -= 1;

        if(count <= -1)
        {
            printf(stderr, "Error with counter (<=-1)\n");
           return -1;
        }

	if(xioctl(dev->fd, VIDIOC_S_INPUT, &count) == -1) {
		print_debug("Error selecting input %d", count);
		return 1;
	}
	return 0;
}
```

Now I'm a bit worried about latency with this camera, since it is streaming with UYUV enconding, which has a lower framerate and larger latency than streaming directly in mjpeg.

But, since streaming works with both webcams and the OPi SH-2035 Cam, the next important think to check with this board is GPIO control via WiringOP to control h-bridges and other hardware required to control the robot.

David-Estevez, 2017-06-04:
It seems that it is indeed possible to harness the power of HW H264 encoding to [stream video with ffmpeg]( https://forum.armbian.com/index.php?/topic/1842-ffmpeg-with-cedrus-h264-hw-encoder-h3-cmos-camera/#entry14157). It might be interesting to test that as it could potentially solve most of our problems with latency.

Other choice with support for HW H264 enconding and similar characteristics as the OPi it the [RPi Zero W](https://www.raspberrypi.org/products/pi-zero-w/). You can even [emulate a network connection through OTG](https://gist.github.com/gbaman/975e2db164b3ca2b51ae11e45e8fd40a) to have a ssh connection similar to the serial tty present by default on the OPi.  Still, the [camera module for the RPi](https://www.raspberrypi.org/documentation/hardware/camera/README.md) is a bit expensive (~25$) compared with the OPi camera.

David-Estevez, 2017-06-06:
GPIOs work as expected using [WiringOP](https://diyprojects.io/orange-pi-armbian-install-wiringop-library-wiringpi-equivalent/). The original code for WiringPI  works almost without changes, although there are some link errors that require to explicitly specify the library to link to. (That code is still on the robot, as it is a hack).

jgvictores, 2017-06-12:
Back on webcam topic, attaching orange-pi-camera (left) vs cheap webcam (right) screenshot.

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
.

David-Estevez, 2017-06-13:
Note that both images were taken at the same distance from the target. I would say that the first one (OPi camera) has better FOV but lower quality / focus whereas the other one (cheap webcam) has a pretty bad FOV but everything is in focus.

David-Estevez, 2017-06-15:
I'm currently working on #4 to provide the new cool robot the ability to know how much battery does it have left.

In addition, I have created the [Cool new robot project](https://github.com/asrob-uc3m/robotDevastation-robots/projects/1) to organize myself (and however is working on this with me at the moment) given all the features required to close this issue.

jgvictores, 2018-06-22:
This issue was moved to asrob-uc3m/robotDevastation-research#12

Closed 2018-06-22.

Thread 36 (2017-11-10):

robotDevastation simulator revival

jgvictores, 2017-11-10:
robotDevastation simulator revival.

We used to have this, called rdSim or similar. We could now do this pretty easily via our robot interface and https://github.com/roboticslab-uc3m/openrave-yarp-plugins (could be implemented here or there).

jgvictores, 2017-12-02:
Blocked by #37

jgvictores, 2017-12-02:
No longer blocked by #37.

jgvictores, 2017-12-02:
Blocked by: https://github.com/roboticslab-uc3m/openrave-yarp-plugins/issues/33

jgvictores, 2017-12-03:
With https://github.com/asrob-uc3m/robotDevastation-openrave-models/issues/1 closed, only blocked by:
- https://github.com/roboticslab-uc3m/openrave-yarp-plugins/issues/33 and other upstream.

jgvictores, 2017-12-06:
Currently:
- RGB blocked by upstream https://github.com/roboticslab-uc3m/openrave-yarp-plugins/issues/48
- Must develop robot controller, could do at https://github.com/roboticslab-uc3m/openrave-yarp-plugins

jgvictores, 2017-12-10:
Interesting lines for robot controller: https://github.com/roboticslab-uc3m/asibot-main/blob/2171d3e6a1ce16ac92f29a939b9dc85db7245dda/src/libraries/RlPlugins/ravebot/IDeviceImpl.cpp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

jgvictores, 2017-12-13:
Robot controller currently at https://github.com/roboticslab-uc3m/openrave-yarp-plugins/tree/rdr-36 starting with https://github.com/roboticslab-uc3m/openrave-yarp-plugins/commit/b430222f4d06b5bc6f11da1db83677dd96b01eb4

jgvictores, 2017-12-13:
As commented https://github.com/roboticslab-uc3m/openrave-yarp-plugins/issues/29#issuecomment-340159347 the code `odevelocity` supports is dead:
```c++
std::stringstream sout,ss;
ss << "setvelocity 3.0 3.0 3.0 3.0 ";
if( ! pcontrol->SendCommand(sout,ss) )
{
    CD_ERROR("failed to send velocity command\n");
    return false;
}
```

jgvictores, 2017-12-13:
Much better with working version, `idealvelocitycontroller`, see https://github.com/roboticslab-uc3m/openrave-yarp-plugins/commit/df2b04e63f7bfb9b6ea479dfc0f1e35f4045b831.

jgvictores, 2017-12-13:
Have working simulated robot: `openrave-YarpPluginLoader-robotmanager.py ` as of https://github.com/roboticslab-uc3m/openrave-yarp-plugins/commit/f4e979210d5ba34dd86ab356fe777f73bad21708

Still blocked by epic https://github.com/roboticslab-uc3m/openrave-yarp-plugins/issues/48 of offscreen render. Must try on old optimus device.

jgvictores, 2018-01-06:
Notes:
1. We want a bash script to launch the one-liner that involves [YarpOpenraveRobotManager](https://github.com/roboticslab-uc3m/openrave-yarp-plugins/tree/00a237e2109ac5029a5f91915d16c3d9cac84fb8/libraries/YarpPlugins/YarpOpenraveRobotManager).
2. [YarpOpenraveRobotManager](https://github.com/roboticslab-uc3m/openrave-yarp-plugins/tree/00a237e2109ac5029a5f91915d16c3d9cac84fb8/libraries/YarpPlugins/YarpOpenraveRobotManager) is very tied to a 4WD robot. Consider the variations and if they will over-populate openrave-yarp-plugins. If we want to move here, consider that we depend on `YarpOpenraveBase` (also affected by https://github.com/roboticslab-uc3m/openrave-yarp-plugins/issues/62).

jgvictores, 2018-01-21:
No longer blocked by https://github.com/roboticslab-uc3m/openrave-yarp-plugins/issues/48!

RD is compatible with https://github.com/roboticslab-uc3m/openrave-yarp-plugins [example](https://github.com/roboticslab-uc3m/openrave-yarp-plugins/blob/a7d73f6e4dc74144a1b601fda3b93f709a584abc/examples/openraveYarpPluginLoader-robotmanager.py):
```bash
COIN_FULL_INDIRECT_RENDERING=1 python examples/openraveYarpPluginLoader-robotmanager.py
```

Choose `ecroSim` as the robot name for connecting. BTW, the camera resolution is tiny, but that is a minor issue which I've documented at https://github.com/asrob-uc3m/robotDevastation-openrave-models/issues/3.

jgvictores, 2018-01-21:
PS: Use https://github.com/roboticslab-uc3m/openrave-yarp-plugins/issues/48 as a guide if have offscreen/indirect rendering issues.

jgvictores, 2018-01-21:
I believe all that's left to do now is document this in https://github.com/asrob-uc3m/robotDevastation-user-manual. Closing this issue and opening an issue there.

Closed 2018-01-21.

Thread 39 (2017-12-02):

Should create AUTHORS.md and place copyright notices at the top of source files

jgvictores, 2017-12-02:
Should create AUTHORS.md and place copyright notices at the top of source files
- Similar done here: https://github.com/asrob-uc3m/robotDevastation/pull/117

jgvictores, 2018-06-22:
This issue was moved to asrob-uc3m/yarp-devices#17

Closed 2018-06-22.

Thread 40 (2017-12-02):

Add travis continuous integration

jgvictores, 2017-12-02:
Add travis continuous integration

PeterBowman, 2018-01-27:
This issue was moved to asrob-uc3m/yarp-devices#3

Closed 2018-01-27.

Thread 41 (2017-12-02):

Require libserial at CMake level for certain devices

jgvictores, 2017-12-02:
Example compilation error:
```
robotDevastation-robots/libraries/YarpPlugins/LaserTowerOfDeathController/LaserTowerOfDeathController.hpp:14:26: fatal error: SerialStream.h: No such file or directory
```

Will happen due to:
- YarpPlugins/LaserTowerOfDeathController/LaserTowerOfDeathController.hpp:#include <SerialStream.h>
- YarpPlugins/EcroWheelController/EcroWheelController.hpp:#include <SerialStream.h>
- YarpPlugins/EcroPwmController/EcroPwmController.hpp:#include <SerialStream.h>

jgvictores, 2018-01-27:
This issue was moved to asrob-uc3m/yarp-devices#2

Closed 2018-01-27.

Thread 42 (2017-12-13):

Merge IRobotManager moveForward/moveBackwards and similar pairs?

jgvictores, 2017-12-13:
Merge [IRobotManager](https://github.com/asrob-uc3m/robotDevastation-robots/blob/e743adcfc864481e0a54918f02ae0c62f77b0d40/libraries/YarpPlugins/IRobotManager.hpp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) `moveForward()`/`moveBackwards()` and similar pairs?

Move, turn, pan, tilt all get (signed) ints as signature. Could be merged to reduce the functions.

PS: I'd go for `double` rather than `int`, and document units (e.g. attempt `m/s` rather than undocumented notion of percentage).

PeterBowman, 2018-01-27:
This issue was moved to asrob-uc3m/yarp-devices#4

Closed 2018-01-27.

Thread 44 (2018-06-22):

Documenting Raspian guide

jgvictores, 2018-06-22:
_From @jgvictores on June 15, 2018 19:53_

Issue to track documentation of Raspian guide. There is some info on the wiki, but this is newer:  Raspbian Stretch Lite (on Raspi 3 B, for https://github.com/asrob-uc3m/rd-ambassador/issues/1 )

- Download Raspbian Stretch Lite image from https://www.raspberrypi.org/downloads/raspbian/
- Unzip and use plain `dd` as a copying mechanism to SD card
- Boot Raspi from SD card
- For keyboard layout, `apt install console-data` for `loadkeys --verbose es` (thanks https://superuser.com/questions/659247/installing-different-keyboard-layout-on-live-debian-image )
- Activate `ssh` as indicated in https://www.raspberrypi.org/documentation/remote-access/ssh/
```bash
sudo apt install git cmake
sudo apt install libjpeg8-dev  # Only required for mjpeg that should improve video comms
# opencv in fact replaces by libjpeg62-dev
sudo apt install --no-install-recommends libopencv-dev  # Only required for opencv_grabber
git clone https://github.com/robotology/yarp
mkdir yarp/build && cd yarp/build
cmake .. -DSKIP_ACE=ON
cmake .. -DENABLE_yarpcar_mjpeg=ON
make -j4 # raspi 3 B
sudo make install
```
https://github.com/asrob-uc3m/yarp-devices/blob/develop/doc/yarp-devices-install.md (except yarp)

- Blocks https://github.com/asrob-uc3m/rd-ambassador/issues/1

_Copied from original issue: asrob-uc3m/robotDevastation-user-manual#12_

jgvictores, 2018-06-22:
```bash
cd  # va a $HOME
git clone git://git.drogon.net/wiringPi # Varios dispositivos Raspi utilizan http://wiringpi.com/download-and-install/
cd wiringPi
./build # Puede requerir contraseña de sudo
cd  # va a $HOME
sudo apt install --no-install-recommends libboost-dev # libserial, a continuación, necesita boost/scoped_ptr.hpp
sudo apt install libserial-dev # Varios dispositivos dependen de libserial
git clone https://github.com/asrob-uc3m/yarp-devices # Descarga devices requeridos
cd yarp-devices && mkdir build && cd build && cmake .. # Configura devices requeridos
make # Compila
sudo make install # Instala :-)
sudo ldconfig # Por si acaso... ;-)
```

jgvictores, 2018-10-18:
Done at https://github.com/asrob-uc3m/robotDevastation-developer-manual/commit/670b7a7ca181a83cd1e9cda05cad8358853f91a4

Closed 2018-10-18.

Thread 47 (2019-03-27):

Design robot that combines best of RD1 and RD2

jgvictores, 2019-03-27:
Design robot that combines:
- Best of RD1:
    - Standard battery holder for standard batteries for motor
    - Use any mobile phone battery for raspi
    - FreeCAD design
- Best of RD2:
    - Webcam support
    - QR support
    - 3rd support for stability (a metal marble on RD2)

Leytha, 2019-06-18:
Camera Holder similar to RD2 one but as a FreeCAD design:
[CameraHolder.fcstd.zip](https://github.com/asrob-uc3m/robotDevastation-robots/files/3303002/CameraHolder.fcstd.zip)

jgvictores, 2020-05-17:
Provided https://github.com/asrob-uc3m/robotDevastation-robots/issues/46#issuecomment-629783236, this issue and similar could be moved to https://github.com/asrob-uc3m/robotDevastation-playground

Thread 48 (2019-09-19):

WiringPi library about to be deprecated

David-Estevez, 2019-09-19:
FYI: https://hackaday.com/2019/09/18/wiringpi-library-to-be-deprecated/

jgvictores, 2019-09-19:
@David-Estevez Thanks for the info!

PeterBowman, 2019-09-19:
Pity we never forked git://git.drogon.net/wiringPi into the asrob-uc3m org, I would do that as soon as the server is up again.

PeterBowman, 2019-09-20:
@jgvictores found a local clone of drogon.net, now it lives in our org at https://github.com/asrob-uc3m/wiringPi.

Next, I'm going to unbreak Travis jobs by fetching these sources instead.

PeterBowman, 2019-09-20:
> Next, I'm going to unbreak Travis jobs by fetching these sources instead.

Done at https://github.com/asrob-uc3m/yarp-devices/commit/44921d4ad9fe707d36ee03693d9293b0f17e9332.

jgvictores, 2020-05-18:
Updated in our install doc at https://github.com/asrob-uc3m/yarp-devices/commit/7b3411f594dbaa288470811ffdf17021135c0785

Closed 2019-09-20.

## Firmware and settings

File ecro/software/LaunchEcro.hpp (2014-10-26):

// -*- mode:C++; tab-width:4; c-basic-offset:4; indent-tabs-mode:nil -*-

#ifndef __RUN_BOT__
#define __RUN_BOT__

#include <yarp/os/RFModule.h>
#include <yarp/os/Module.h>
#include <yarp/os/Network.h>
#include <yarp/os/Port.h>
#include <yarp/os/BufferedPort.h>

#include <yarp/dev/PolyDriver.h>

#include "RdMacros.hpp"

#define DEFAULT_TYPE "nanobot"
#define DEFAULT_PREFIX "1/ecro"
#define DEFAULT_CAMERA "on"

using namespace yarp::os;
using namespace yarp::dev;

/**
 * @ingroup LaunchEcro
 *
 * The LaunchEcro class tests the Pwm class as a controlboard.
 * 
 */
class LaunchEcro : public RFModule {

    public:
        LaunchEcro();
        bool configure(ResourceFinder &rf);

    protected:
        yarp::dev::PolyDriver cameraDevice;
        yarp::dev::PolyDriver robotDevice;

        virtual bool updateModule();
        virtual bool close();

//        double getPeriod();
//        bool interruptModule();
//        int period;

        std::string camera;

};

#endif  // __RUN_BOT__

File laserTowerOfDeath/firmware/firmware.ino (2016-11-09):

//--------------------------------------------------------------
//-- A server for byte-sized commands, first 2 most significant
//-- bits reserved for direction, rest for PWM ms.
//--------------------------------------------------------------
//-- (c) Juan G Victores, Jun 2012
//-- (c) Juan Gonzalez-Gomez (Obijuan), Dec 2011
//-- GPL license
//--------------------------------------------------------------

#include <Servo.h> 

//-- Mapping between the servo name (in the skymega board) and the
//-- arduino pins
const int SERVO_0 = 9;
const int SERVO_1 = 10;

//-- Array for accesing the 2 servos
Servo myservo[2];  

int incomingByte = 0;   // for incoming serial data

void setup() 
{
  //-- Attaching the 2 servos
  myservo[0].attach(SERVO_0);
  myservo[1].attach(SERVO_1);
  
  Serial.begin(9600);
}  

void loop() { 
  
    if (Serial.available() > 0) {  // wait to receive data...
        // read the incoming byte:
        incomingByte = Serial.read();

        // say what you got:
        Serial.print("I received 0x");
        Serial.println(incomingByte, HEX);
        
        int dir = incomingByte >> 6;
        Serial.print("--> direction: ");
        Serial.println(dir, DEC);

        int vel = (incomingByte & 0x3f) * 46;
        Serial.print("--> velocity: ");
        Serial.println(vel, DEC);

        myservo[dir].writeMicroseconds(vel);
        
/*        if(incomingByte==97) {
            Serial.println("It was a");
            myservo[0].writeMicroseconds(1500);
        } else if (incomingByte==98) {
            Serial.println("It was b");
            myservo[0].writeMicroseconds(2100);
        } else if (incomingByte==99) {
            Serial.println("It was c");
            myservo[0].writeMicroseconds(900);
        }*/
        
    }       
} 

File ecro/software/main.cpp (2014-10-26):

/*
 * Copyright: (C) 2010 RobotCub Consortium
 * Author: Paul Fitzpatrick
 * CopyPolicy: Released under the terms of the LGPLv2.1 or later, see LGPL.TXT
 */

#include <stdio.h>
#include <yarp/os/all.h>
#include <yarp/dev/all.h>

#include "RdMacros.hpp"
#include "LaunchEcro.hpp"

using namespace yarp::os;
using namespace yarp::dev;

YARP_DECLARE_PLUGINS(EcroYarp);

int main(int argc, char *argv[]) {

    YARP_REGISTER_PLUGINS(EcroYarp);

    ResourceFinder rf;
    rf.setVerbose(false);
    rf.setDefaultContext("launchEcro/conf");
    rf.setDefaultConfigFile("launchEcro.ini");
    rf.configure("ECRO_YARP_ROOT", argc, argv);

    RD_INFO("Checking for yarp network...\n");
    Network yarp;
    if (!yarp.checkNetwork()) {
        RD_ERROR("Found no yarp network (try running \"yarpserver &\"), bye!\n");
        return -1;
    }
    RD_SUCCESS("Found yarp network.\n");

    LaunchEcro mod;
    return mod.runModule(rf);
}

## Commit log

2014-10-19 add freecad models and generated stl models
    [rdSopportBack.FCStd, rdSopportBack.stl, rdSopportFront.FCStd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]
2014-10-26 add code for arduino nano of latest ecro version
2014-10-26 code for ecro on-board cpu
2015-04-06 PwmBot in rd namespace
2015-04-06 avoid using yarp namespace in LaunchRd1 and main
    [main.cpp]
2015-04-06 renaming pwmbot files to match classes from which they inherit
2015-04-06 pwmbot implement IEncodersTimedImpl to be able to be wrapped by controlboardwrapper2
2015-04-06 PwmBot comment out output that is too verbose in controlboardwrapper2 stream
2015-04-20 velocityMove for DoubleHBridge
2015-04-20 velocityMove on gpios.size()/2
2015-04-20 New Base For rd2
    [rd2Base.STL]
2015-04-22 renaming pwmbots
2015-04-22 renaming pwmbots to plural
2015-04-22 renaming pwmbots (file names)
2015-04-22 OnePwmMotors and TwoPwmMotors drop default num motors
2015-04-23 rd2Base Updated
    [rd2Base.STL, rd2BaseV1_0.STL]
2015-04-27 up rd2 wheel for printing
    [rd2Wheel.STL, rd2Wheel.fcstd]
2015-04-29 add drills to rd2Wheel
    [rd2Wheel.STL, rd2Wheel.fcstd]
2015-04-29 OnePwmMotors normalize velocities
2015-04-30 Upper Part for Rd2
    [rd2TopV1_0.STL]
2015-05-04 More space for black plastic piece.
    [rd2Wheel.STL, rd2Wheel.fcstd]
2015-05-07 More space for piece.
    [rd2Wheel.STL, rd2Wheel.fcstd]
2015-06-01 Upper Part for Rd2 V1.1
    [rd2TopV1_0.STL, rd2TopV1_1.STL]
2015-06-01 Wheel bigger holes.
    [rd2Wheel.STL, rd2Wheel.fcstd]
2015-09-16 rd2 New Camera Top
    Until now we were developing an unique top part for the robot. After
    having some problems due to the diferent configurations that is posible
    to have, we change the concept. Now, the top of the robot we will made
    of several parts that can be combined in order to support more
    hardware(raspberry pi,odrid,beaglebone).
    [rd2CameraTopV1_0.STL, rd2TopV1_1.STL]
2015-10-02 New support for the battery conector
    Only works with china batteries
    [rd2SoporteBateria_V1.0.STL]
2015-10-04 MT7601 driver [copy from porjo], put in /lib/firmware for raspi 4.1.9+
2015-10-06 rd2 Hardware Finished
    Right Now all the pieces for making your own rd2 are avaliable. We will
    documentate this model raspberrypi1B.
    Also is expected to fit we other model of raspberry with some
    modifications and with other boards as well.
    Cases are not desing yet, the electronics will be visible
    [rd2SoporteRaspberry1B_(2)V1_0.STL, rd2SoporteRaspberry1B_V1_0.STL]
2016-06-08 add Robot and camera movement related functions
2016-06-15 RdFakeMotors CD_INFO of velocity
2016-11-01 disable default compilation of devices wrapped by controlboardwrapper2
2016-11-09 [hot-fix] best protocol ever :lipstick:
    [firmware.ino]
2017-01-13 Add freecad files for necro supports
    [supportA.fcstd, supportB.fcstd]
2017-01-13 Add stl files for necro supports
    [supportA.stl, supportB.stl]
2017-01-14 Add freecad files for motor driver holder
    [motorDriverHolder.fcstd]
2017-01-14 Add stl files for motor driver holder
    [motorDriverHolder.stl]
2017-01-26 Add front holes template
    [front template.dxf, front template.fcstd]
2017-01-26 Add back holes template
    [back template.dxf, back template.fcstd]
2017-01-26 Add template for motor holders
    [motor holder.dxf]
